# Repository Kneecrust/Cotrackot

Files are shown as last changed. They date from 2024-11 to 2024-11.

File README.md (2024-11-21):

# Cotrackot
A simple, 40 key, wireless, unibody with T460s Trackpoint compatibility named 'Cotrackot'.
Fell in love with Aki's 'Cocot46+' and it inspired me to design this keyboard.

Some details:
1. Choc v1 - Hotswap - MX spaced - index & inner-index columns set to ortholinear for ideal Trackpoint placement.
2. On/Off switch 'jumper on header style' - Placing the jumper over the left and middle pins connects the battery, placing it over the middle and right pins disconnects the battery.
3. 15° angle between the two sides.
4. Pins exposed for Trackpoint: VCC, GND, CLK (P0), DATA (P1), RST (P9).
5. Custom 3DP LDSA keycaps adjusted for MX spacing.
6. Custom 3DP Trackpoint extension pin optimized for FDM printing.

______
Important note on Ergogen yaml:
GPIO are not correctly assigned. 😅
I dealt with that in Kicad directly rather than doing that in Ergogen.

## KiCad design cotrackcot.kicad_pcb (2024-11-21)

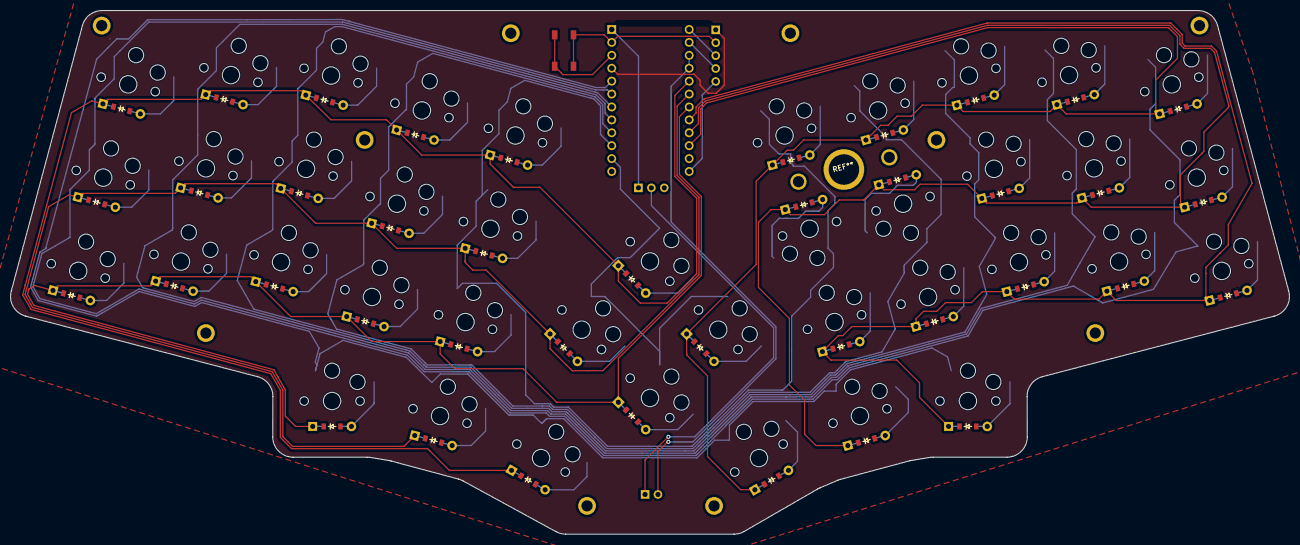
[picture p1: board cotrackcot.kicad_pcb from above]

Board: 2 copper layers, 251.6 x 103.0 mm, 83 parts (0 on the bottom side), 59 nets.

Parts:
B1: SW_TACT_ALPS_SKQGABE010
D1, D2, D3, D4, D5, D6, D7, D8, D9, D10, D11, D12, D13, D14, D15, D16, D17, D18, D19, D20, D21, D22, D23, D24, D25, D26, D27, D28, D29, D30, D31, D32, D33, D34, D35, D36, D37, D38, D39, D40: ComboDiode
MCU1: ProMicro
S1, S2, S3, S4, S5, S6, S7, S8, S9, S10, S11, S12, S13, S14, S15, S16, S17, S18, S20, S21, S22, S23, S24, S25, S26, S27, S28, S29, S30, S31, S32, S33, S34, S35, S36, S37, S38, S39, S40: PG1350 - Choc Hotswap Basic
S19: PG1350
T460S: T460S; PinHeader_1x05_P2.54mm_Vertical

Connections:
Col_1: MCU1.11, S1.1, S2.1, S3.1, S4.1
Col_2: MCU1.10, S17.1, S18.1, S19.1, S32.1, S33.1, S34.1
Col_3: MCU1.9, S14.1, S15.1, S16.1, S29.1, S30.1, S31.1
Col_4: MCU1.8, S11.1, S12.1, S13.1, S26.1, S27.1, S28.1
Col_5: MCU1.7, S8.1, S9.1, S10.1, S23.1, S24.1, S25.1
Col_6: MCU1.6, S5.1, S6.1, S7.1, S20.1, S21.1, S22.1
Col_7: MCU1.5, S35.1, S36.1, S37.1, S38.1, S39.1, S40.1
GND: B1.1, MCU1.2, MCU1.15, MCU1.16, T460S.2
P0: MCU1.14, T460S.4
P1: MCU1.13, T460S.3
P9: MCU1.24, T460S.5
RST: B1.2, MCU1.3
Row_1: D4.1, D7.1, D10.1, D13.1, D16.1, D19.1, D37.1, MCU1.17
Row_2: D2.1, D6.1, D9.1, D12.1, D15.1, D18.1, D36.1, MCU1.18
Row_3: D1.1, D5.1, D8.1, D11.1, D14.1, D17.1, D35.1, MCU1.19
Row_4: D3.1, D22.1, D25.1, D28.1, D31.1, D34.1, D40.1, MCU1.22
Row_5: D21.1, D24.1, D27.1, D30.1, D33.1, D39.1, MCU1.21
Row_6: D20.1, D23.1, D26.1, D29.1, D32.1, D38.1, MCU1.20
VCC: MCU1.4, T460S.1
home_home: D36.2, S36.2
index_bottom: D14.2, S14.2
index_home: D15.2, S15.2
index_top: D16.2, S16.2
inner_bottom: D17.2, S17.2
inner_home: D18.2, S18.2
inner_home_thumb_left: D35.2, S35.2
inner_top: D19.2, S19.2
left_bottom: D2.2, S2.2
left_home: D1.2, S1.2
middle_bottom: D11.2, S11.2
middle_home: D12.2, S12.2
middle_top: D13.2, S13.2
mirror_home_home: D39.2, S39.2
mirror_index_bottom: D29.2, S29.2
mirror_index_home: D30.2, S30.2
mirror_index_top: D31.2, S31.2
mirror_inner_bottom: D32.2, S32.2
mirror_inner_home: D33.2, S33.2
mirror_inner_home_thumb: D38.2, S38.2
mirror_inner_top: D34.2, S34.2
mirror_middle_bottom: D26.2, S26.2
mirror_middle_home: D27.2, S27.2
mirror_middle_top: D28.2, S28.2
mirror_outer_home: D40.2, S40.2
mirror_pinky_bottom: D20.2, S20.2
mirror_pinky_home: D21.2, S21.2
mirror_pinky_top: D22.2, S22.2
mirror_ring_bottom: D23.2, S23.2
mirror_ring_home: D24.2, S24.2
mirror_ring_top: D25.2, S25.2
outer_home: D37.2, S37.2
pinky_bottom: D5.2, S5.2
pinky_home: D6.2, S6.2
pinky_top: D7.2, S7.2
right_bottom: D4.2, S4.2
right_home: D3.2, S3.2
ring_bottom: D8.2, S8.2
ring_home: D9.2, S9.2
ring_top: D10.2, S10.2
